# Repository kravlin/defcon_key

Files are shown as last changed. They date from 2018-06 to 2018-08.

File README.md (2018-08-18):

# DEFCON 26 INFOBOOTH Key
## The Key to Misinformation

This is the Infobooth Key Badge for DEFCON 26. Created at the behest of Mello and Littlebruzer. 

## Bill of Materials

* [6mm square Buttons](https://www.adafruit.com/product/367) - I couldn't find this on mouser, and I needed 60 of them.
* [Coin Cell Battery Holder](https://www.mouser.com/ProductDetail/Eagle-Plastic-Devices/122-2520-GR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) - This stands off the board. This is good for me, but finding one without the standoffs would be good.
* [ATTINY84](https://www.mouser.com/ProductDetail/556-ATTINY84A-PU)
* [10K Pulldown Resistor](https://www.mouser.com/ProductDetail/603-MFR-25FRF5210K)
* [3mm Amber LEDs](https://www.mouser.com/ProductDetail/Vishay-Semiconductors/TLHE4600?qs=%2fjqivxn91ccKeAJQzr9uyA==)
* [5mm Red LEDs](https://www.mouser.com/ProductDetail/Kingbright/WP63SRD?qs=7QlcvZZejStVbcM3wnr71w==)
* [57.6ohm Resistor](https://www.mouser.com/ProductDetail/KOA-Speer/MF1-4DC57R6F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) - for the eye LEDs. Only 1 per badge.
* [110ohm Resistor](https://www.mouser.com/ProductDetail/603-MFR-25FBF52-110R) - 8 per badge. For amber LEDs
* CR2032 battery. Avalible...anywhere?

## Code

The code is fairly simple. it just creates a  bunch of cool animations. It was originally supposed to do game state, but the game didn't get finished before I had to make the badge happen, so I just dumped in the animations. There's a goal for DEFCON 27 to have the code re-finished and therefore be able to re-program everyone's badge with a game.

## Special Thanks

Mouse - for help with the pulldown resistor, as well as general cheerleadership :)

Mello - for running the Infobooth that i've been calling home the last 5 years.

Littlebruzer - for encouraging me to do this. I wouldn't probably have ever made this without your pushing me to work on it.

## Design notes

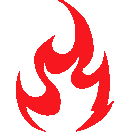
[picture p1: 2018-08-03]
aku eyes.bmp

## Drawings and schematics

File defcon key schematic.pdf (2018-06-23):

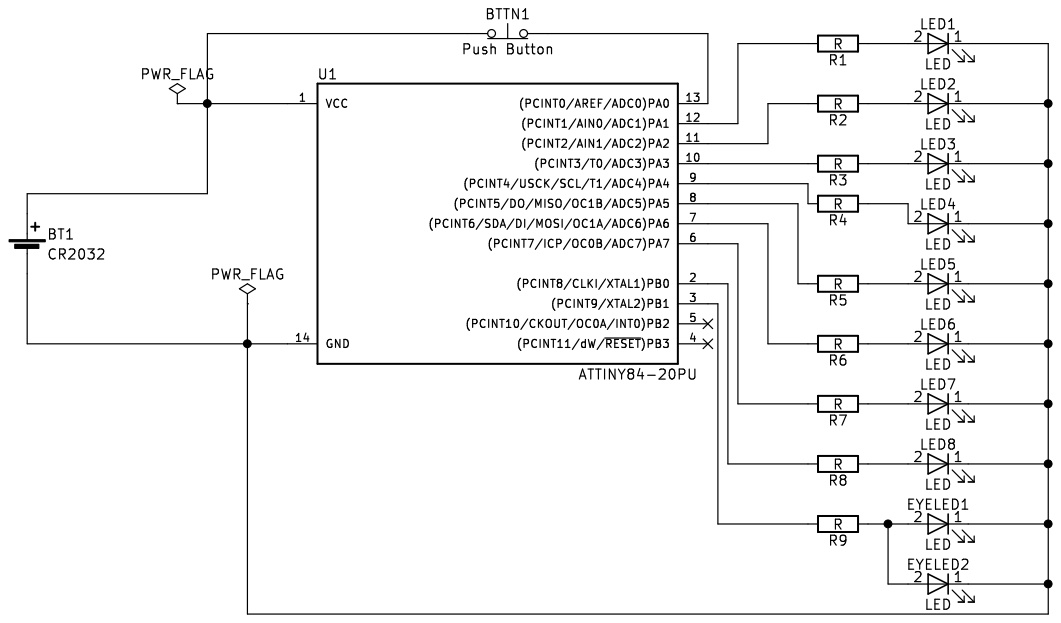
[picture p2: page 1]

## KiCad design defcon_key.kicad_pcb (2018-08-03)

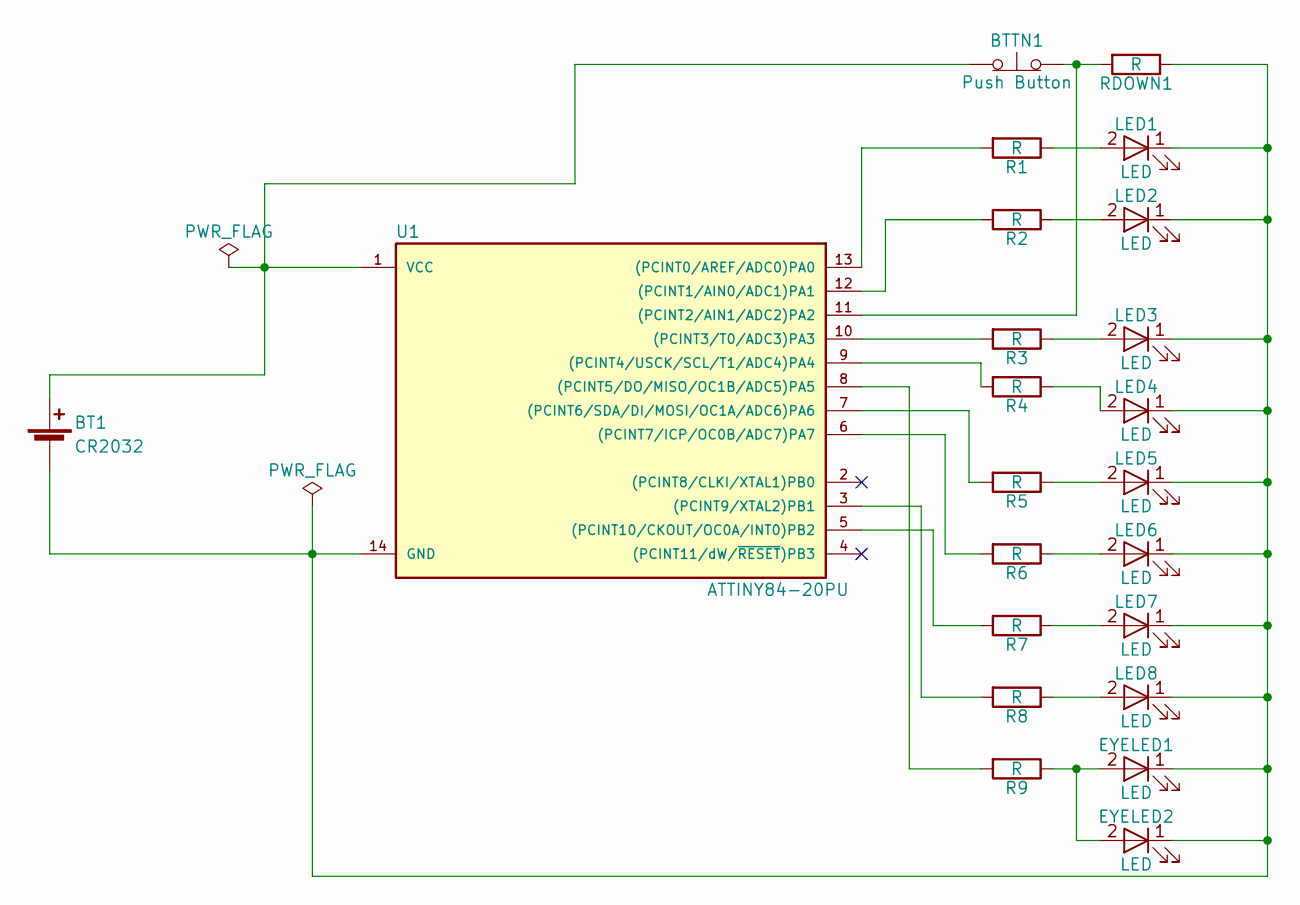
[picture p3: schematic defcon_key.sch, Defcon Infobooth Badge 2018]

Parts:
BT1: CR2032; Keystone_103_1x20mm-CoinCell
BTTN1: Push Button; SW_PUSH_6mm
EYELED1, EYELED2: LED; LED_D5.0mm
LED1, LED2, LED3, LED4, LED5, LED6, LED7, LED8: LED; LED_D3.0mm
R1, R2, R3, R4, R5, R6, R7, R8, R9: R; R_Axial_DIN0207_L6.3mm_D2.5mm_P7.62mm_Horizontal
RDOWN1: R; R_Axial_DIN0207_L6.3mm_D2.5mm_P7.62mm_Horizontal
U1: ATTINY84-20PU; DIP-14_W7.62mm

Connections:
unnamed: BT1.1 (+), BTTN1.1 (A), U1.1 (VCC)
unnamed: BT1.2 (-), EYELED1.1 (K), EYELED2.1 (K), LED1.1 (K), LED2.1 (K), LED3.1 (K), LED4.1 (K), LED5.1 (K), LED6.1 (K), LED7.1 (K), LED8.1 (K), RDOWN1.1, U1.14 (GND)
unnamed: BTTN1.2 (B), RDOWN1.2, U1.11 ((PCINT2/AIN1/ADC2)PA2)
unnamed: EYELED1.2 (A), EYELED2.2 (A), R9.1
unnamed: LED1.2 (A), R1.1
unnamed: LED2.2 (A), R2.1
unnamed: LED3.2 (A), R3.1
unnamed: LED4.2 (A), R4.1
unnamed: LED5.2 (A), R5.1
unnamed: LED6.2 (A), R6.1
unnamed: LED7.2 (A), R7.1
unnamed: LED8.2 (A), R8.1
unnamed: R1.2, U1.13 ((PCINT0/AREF/ADC0)PA0)
unnamed: R2.2, U1.12 ((PCINT1/AIN0/ADC1)PA1)
unnamed: R3.2, U1.10 ((PCINT3/T0/ADC3)PA3)
unnamed: R4.2, U1.9 ((PCINT4/USCK/SCL/T1/ADC4)PA4)
unnamed: R5.2, U1.7 ((PCINT6/SDA/DI/MOSI/OC1A/ADC6)PA6)
unnamed: R6.2, U1.6 ((PCINT7/ICP/OC0B/ADC7)PA7)
unnamed: R7.2, U1.5 ((PCINT10/CKOUT/OC0A/INT0)PB2)
unnamed: R8.2, U1.3 ((PCINT9/XTAL2)PB1)
unnamed: R9.2, U1.8 ((PCINT5/DO/MISO/OC1B/ADC5)PA5)

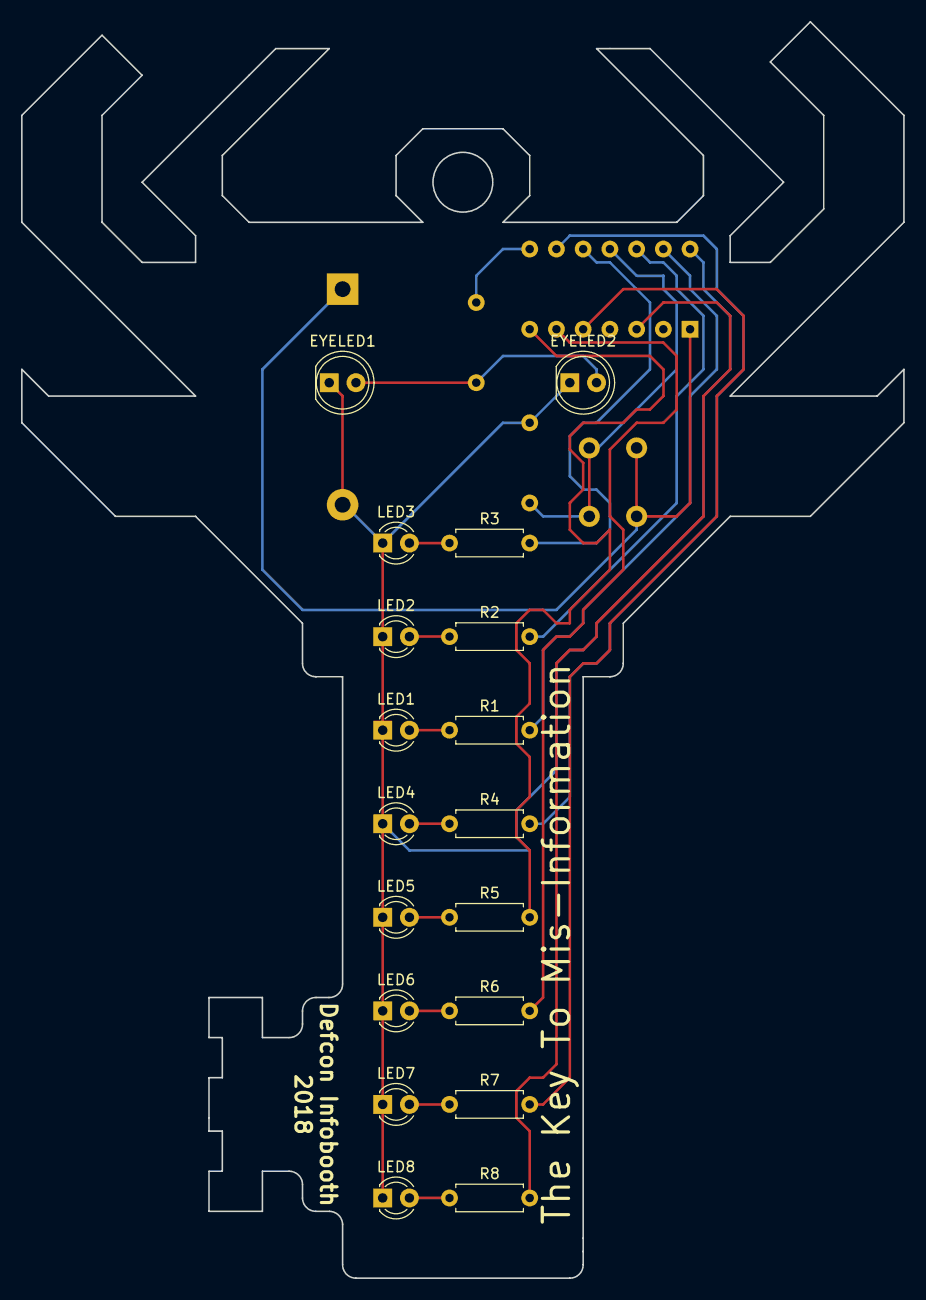
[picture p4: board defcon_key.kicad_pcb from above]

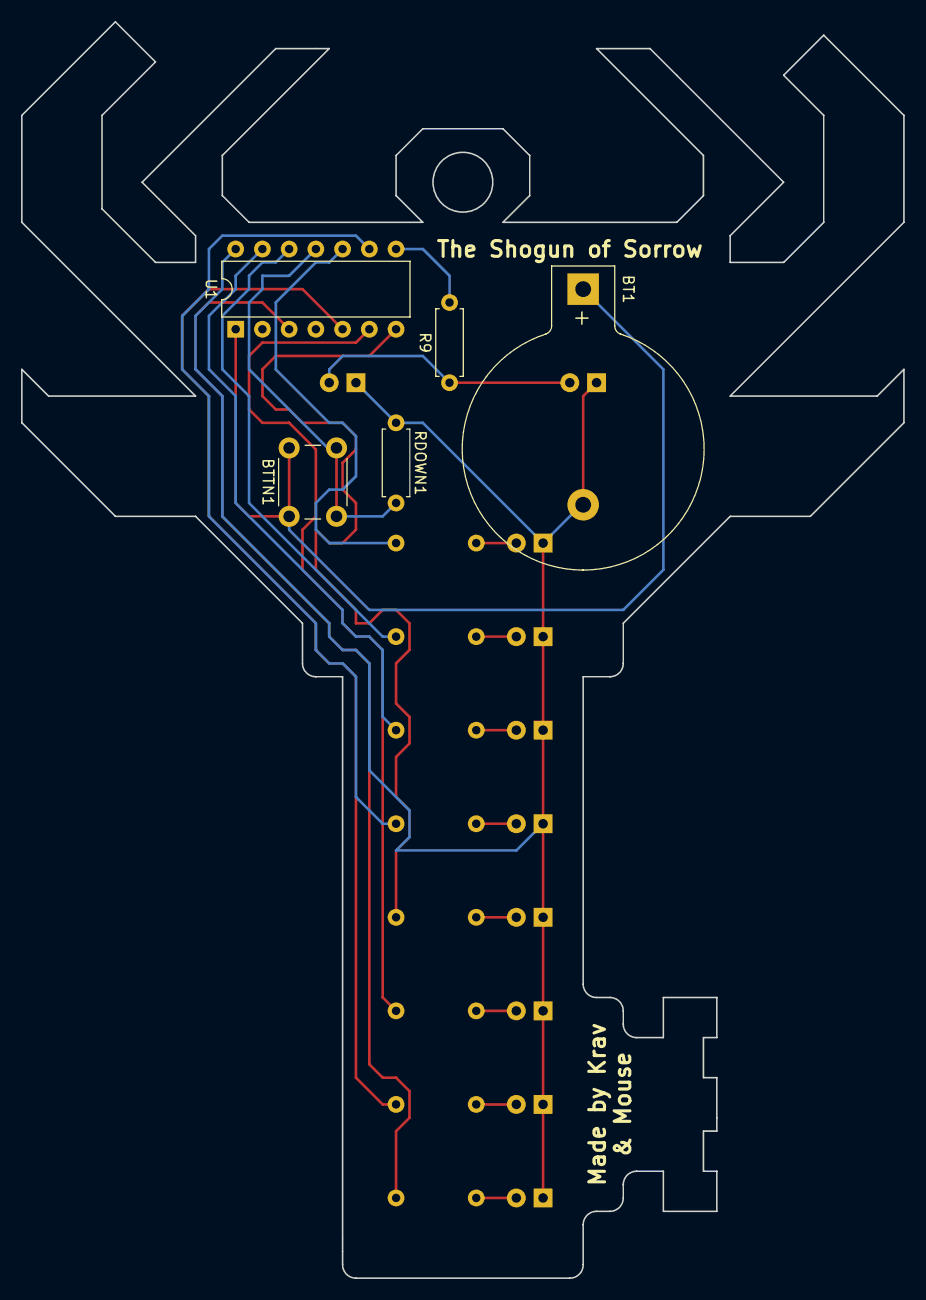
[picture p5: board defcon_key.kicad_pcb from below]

Board: 2 copper layers, 83.8 x 119.4 mm, 23 parts (5 on the bottom side), 21 nets.

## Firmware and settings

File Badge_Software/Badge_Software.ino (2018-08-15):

int eyePin = 5;
int buttonPin = 2;
int onPin = 1;
int buttonState = 0;
int currStep = 0;
int eye_brightness = 0;
int fadeAmount = 5;
int mode = 0;
int ledPins [8] = {3, 1, 0, 4, 6, 7, 8, 9};
int visualizer = 0;
int visualizerStep = -1;
int visualizerDir = 1;
int slowFill = 0;

void setup() {
  // put your setup code here, to run once:
  for (int i=0; i < 8; i++){
    pinMode(ledPins[i], OUTPUT);
  }
  pinMode(eyePin, OUTPUT);
  pinMode(buttonPin, INPUT);
  digitalWrite(eyePin, HIGH);
}

void visualize(){
  if(visualizer == 0){
    //This is effectively the "off but still eyes" choice
    delay(1);
  }
  else if(visualizer == 1){
    fillDown();
  }else if(visualizer == 2){
    fillUp();
  }else if(visualizer == 3){
    traceLight();
  }else if(visualizer == 4){
    traceDark();
  }else if(visualizer == 5){
    expand();
  }else if(visualizer == 6){
    contract();
  }else if(visualizer == 7){
    slowfillUp();
  }
}

void cycleVisualizer(){
  if(visualizer == 7){
    visualizer = 0;
  }
  else{
    visualizer++;
  }
  for (int i=0; i<8; i++){
    digitalWrite(ledPins[i], LOW);
  }
  visualizerStep = -1;
  visualizerDir = 1;
}

//////VISUALIZERS GO HERE//////

void fillDown() {
  visualizerStep = visualizerStep + visualizerDir;
  if(visualizerStep > -1 && visualizerStep < 8){
    if(visualizerDir == 1){
      digitalWrite(ledPins[visualizerStep], HIGH);
    }else{
      digitalWrite(ledPins[visualizerStep], LOW);
    }
  }
  else{
    visualizerDir = -visualizerDir;
  }
}

void fillUp(){
  visualizerStep = visualizerStep + visualizerDir;
  if(visualizerStep > -1 && visualizerStep < 8){
    if(visualizerDir == 1){
      digitalWrite(ledPins[7-visualizerStep], HIGH);
    }else{
      digitalWrite(ledPins[7-visualizerStep], LOW);
    }
  }
  else{
    visualizerDir = -visualizerDir;
  }
}

void traceLight(){
  if(visualizerStep == -1){
     digitalWrite(ledPins[++visualizerStep], HIGH);   
  }else{
    if(visualizerDir == 1){
      digitalWrite(ledPins[visualizerStep++], LOW);
      digitalWrite(ledPins[visualizerStep], HIGH);
    }else{
      digitalWrite(ledPins[visualizerStep--], LOW);
      digitalWrite(ledPins[visualizerStep], HIGH);
    }
    if(visualizerStep <= 0 || visualizerStep >= 7){
      visualizerDir = -visualizerDir;
    }   
  }
}

void traceDark(){
  //This is a setup for doing this well, instead of poorly.
  if(visualizerStep == -1){
    for(int i= 1; i <= 7; i++){
      digitalWrite(ledPins[i], HIGH);
    }
    visualizerStep++;
  }else{
    if(visualizerDir == 1){
      digitalWrite(ledPins[visualizerStep++], HIGH);
      digitalWrite(ledPins[visualizerStep], LOW);
    }else{
      digitalWrite(ledPins[visualizerStep--], HIGH);
      digitalWrite(ledPins[visualizerStep], LOW);
    }
    if(visualizerStep <= 0 || visualizerStep >= 7){
      visualizerDir = -visualizerDir;
    }
  }
}

void expand(){
  visualizerStep = visualizerStep + visualizerDir;
  if(visualizerDir == 1){
    digitalWrite(ledPins[3-visualizerStep], HIGH);
    digitalWrite(ledPins[4+visualizerStep], HIGH);
  }else{
    digitalWrite(ledPins[3-visualizerStep], LOW);
    digitalWrite(ledPins[4+visualizerStep], LOW);
  }
  if(visualizerStep <= -1 || visualizerStep >= 4){
    visualizerDir = -visualizerDir;
  }
}

void contract(){
  visualizerStep = visualizerStep + visualizerDir;
  if(visualizerDir == 1){
    digitalWrite(ledPins[visualizerStep], HIGH);
    digitalWrite(ledPins[7-visualizerStep], HIGH);
  }else{
    digitalWrite(ledPins[visualizerStep], LOW);
    digitalWrite(ledPins[7-visualizerStep], LOW);
  }
  if(visualizerStep <= -1 || visualizerStep >= 4){
    visualizerDir = -visualizerDir;
  }
}

void slowfillUp(){
  if(visualizerStep == -1){
    visualizerStep++;
  }
  if(visualizerStep < 8){
    if(slowFill > 0){
      digitalWrite(ledPins[slowFill-1], LOW);
    }
    digitalWrite(ledPins[slowFill], HIGH);
    if(slowFill == 7-visualizerStep){
      visualizerStep++;
      slowFill = 0;
    }else{
      slowFill++;
    }
  }else{
    int evenOrOdd = visualizerStep % 2;
    if(evenOrOdd == 1){
      for(int i = 0; i < 8; i++){
        digitalWrite(ledPins[i], LOW);
      }
    }else{
      for(int i = 0; i < 8; i++){
        digitalWrite(ledPins[i], HIGH);
      }
    }
    visualizerStep++;
    if(visualizerStep == 14){
      visualizerStep = 0;
      clearLED();
    }
  }
}


/////EYE CODE///////////////////////

void fadeEyes(){
  analogWrite(eyePin, eye_brightness);
  eye_brightness = eye_brightness + fadeAmount;
  if(eye_brightness <= 0 || eye_brightness >= 255) {
    fadeAmount = -fadeAmount;
  }
}

//////BUTTON CHECKING CODE/////////

void clearLED(){
  for(int i = 0; i < 8; i++){
    digitalWrite(ledPins[i], LOW);
  }
}

void checkButton(){
  int buttonPushed = digitalRead(buttonPin);
  if(buttonPushed == HIGH){
    buttonState++;
  }
  if(buttonPushed == LOW && buttonState > 0){
    cycleVisualizer();
    buttonState = 0;
  }
}

void loop() {
  if((currStep % 64) == 0){
    visualize();
  }
  if((currStep % 16) == 0){
    fadeEyes();
  }
  if((currStep % 4) == 0){
    checkButton();     
  }
  delay(6);
  if(currStep == 128){
    currStep = 0;
  }
  currStep++;
}
